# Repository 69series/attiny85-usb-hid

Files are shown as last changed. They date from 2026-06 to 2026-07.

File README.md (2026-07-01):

# ATtiny85 USB HID Keyboard

A fully custom USB HID keyboard dongle built on ATtiny85 — bare metal C firmware,
custom PCB designed in KiCad 10, no Arduino, no HAL, no bootloader abstractions.
Plug it into any USB port and it enumerates as a real HID keyboard device.

---

# ATtiny85 USB HID Keyboard








A fully custom USB HID keyboard dongle...

## What it does

Plugs directly into a USB-A port and acts as an autonomous HID keyboard.
Planned automation payloads (see `firmware/` for examples):

- One-click temp folder cleaner (`Win+R → %temp% → Ctrl+A → Shift+Del`)
- Stored credential injector (password manager dongle)
- Custom keyboard macro sequences
- Any HID keystroke automation — limited only by firmware logic

---

## Hardware

| Part | Value | Package |
|---|---|---|
| U1 | ATtiny85-20SU | SOIC-8 |
| R1, R2 | 68Ω | 1206 |
| R3 | 1.5kΩ (pull-up) | 1206 |
| R4 | 1.5kΩ (LED) | 1206 |
| C1 | 100nF | 0805 |
| D1, D2 | 3.6V Zener | SOD-123 |
| D3 | LED | 0402 |
| J1 | USB-FX | Custom PCB-edge footprint |

**PCB:** 31.31 × 11.8 × 0.8mm — slides directly into USB-A female socket.
Custom USB-FX footprint — PCB edge pads act as USB-A plug contacts.
Designed in KiCad 10. Ground pour on F.Cu.

**Schematic:** `docs/schematic.png`
**PCB Layout:** `docs/pcb.png`
**3D Render:** `docs/3dpcb_front.png` / `docs/3dpcb_back.png`
**Gerbers + BOM:** `hardware/fabrication/`

---

### Schematic
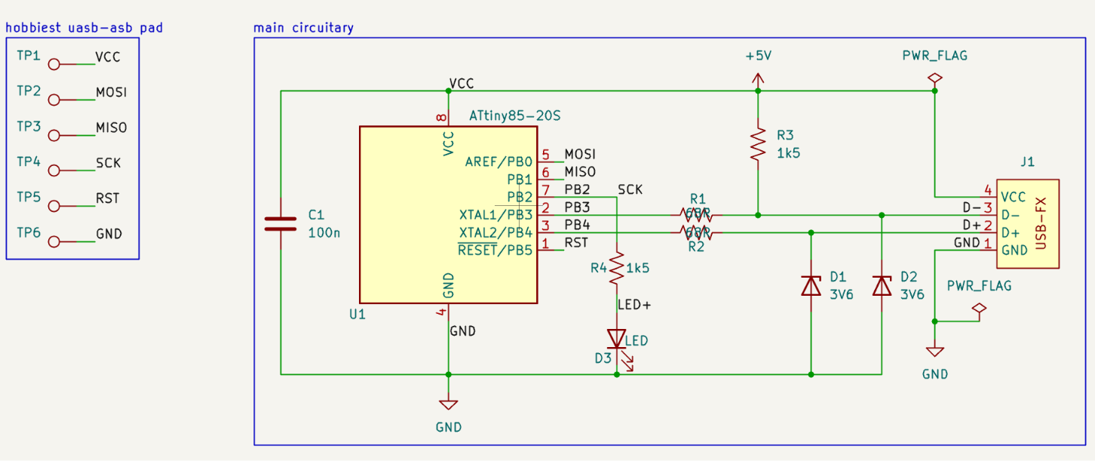
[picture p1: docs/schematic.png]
Schematic


### PCB Layout
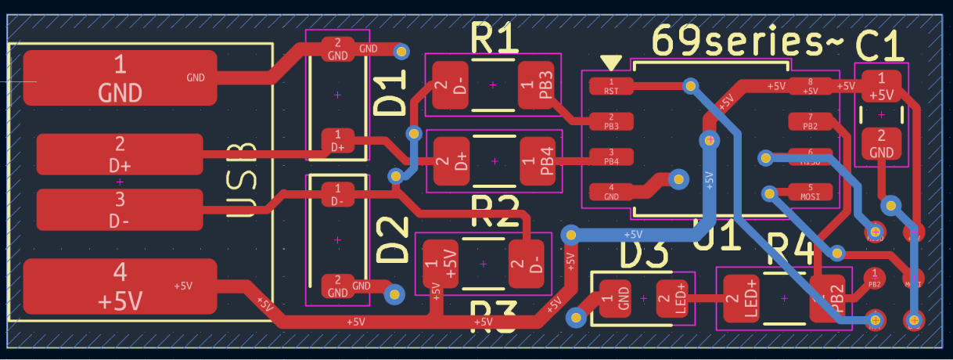
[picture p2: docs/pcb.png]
PCB Layout


### 3D Render
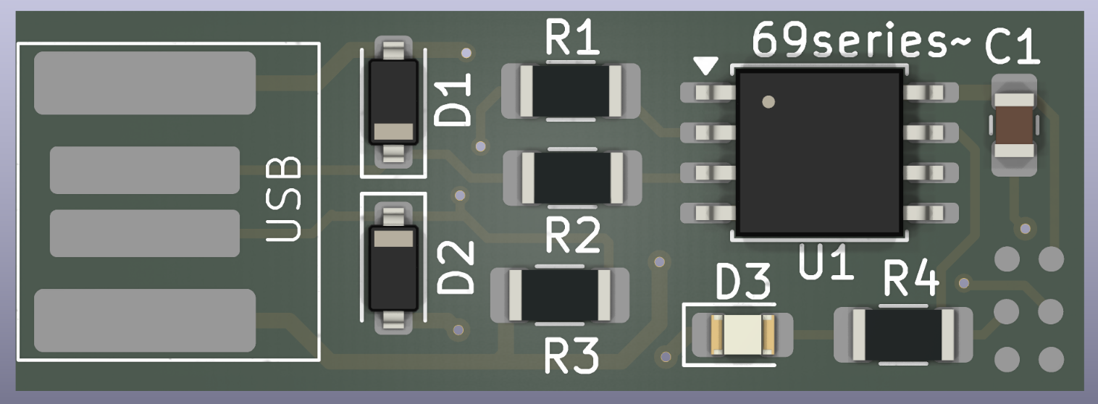
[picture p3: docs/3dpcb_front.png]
PCB Front

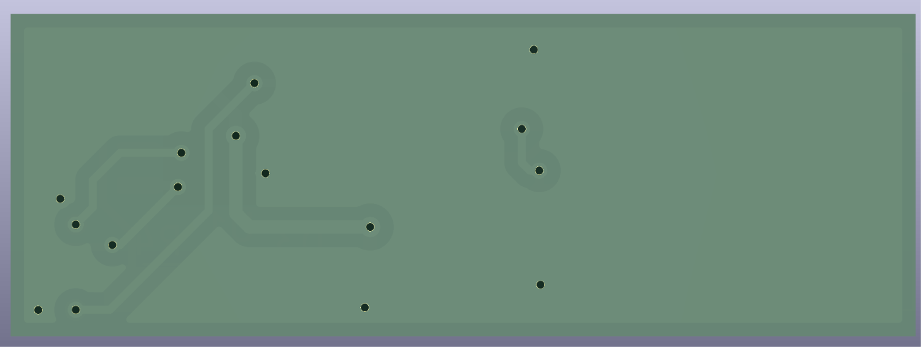
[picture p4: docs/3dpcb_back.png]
PCB Back


## Firmware

Pure bare-metal C. No Arduino core, no HAL, no bootloader.
Uses the V-USB library (obdev, v20121206) for software USB bit-banging on PB3/PB4.

**Toolchain:** avr-gcc (WinAVR), avrdude, VS Code

### Build and flash

```bash
cd firmware
make
make fuses
make flash
```

Or use the included automation script:

```bash
69s.bat -unlock -17A
```

### Fuse bits

```bash
avrdude -c usbasp -p attiny85 -U lfuse:w:0xE1:m -U hfuse:w:0xDD:m
```

- `lfuse 0xE1` — internal 16.5MHz PLL oscillator (required for V-USB timing)
- `hfuse 0xDD` — RESET enabled, SPI programming on

### Pin mapping

| ATtiny85 Pin | Function |
|---|---|
| PB3 (pin 2) | USB D− |
| PB4 (pin 3) | USB D+ |
| PB2 (pin 7) | Status LED |
| PB0 (pin 5) | ICSP MOSI / TP2 |
| PB1 (pin 6) | ICSP MISO / TP3 |
| PB2 (pin 7) | ICSP SCK / TP4 |
| PB5 (pin 1) | RESET / TP5 |

---

## Project Structure

```
attiny85-usb-hid/
├── docs/                     # Schematic, PCB renders, design notes
│   ├── schematic.png
│   ├── pcb.png
│   ├── 3dpcb_front.png
│   ├── 3dpcb_back.png
│   └── design-notes.md
├── firmware/                 # Bare metal C firmware
│   ├── main.c                # Main application
│   ├── usbconfig.h           # V-USB hardware configuration
│   ├── Makefile
│   ├── 69s.bat               # One-shot build+flash automation
│   └── usbdrv/               # V-USB library (obdev v20121206)
├── hardware/
│   ├── fabrication/          # Gerbers, BOM, positions for JLCPCB
│   │   ├── t85-gerber.zip
│   │   ├── bom.csv
│   │   └── positions.csv
│   ├── hardware_prototype/   # Prototype build photos, all versions
│   │   ├── spider_config.jpeg        # Initial 6-wire ICSP test setup
│   │   ├── vers_1_front.jpeg         # Version 1 prototype
│   │   ├── vers_1_back.jpeg
│   │   ├── final_cleanup_version_front.jpg  # Final build (PB4 hot-wired)
│   │   └── final_cleanup_version_back.jpg
│   ├── t85-usb.kicad_sch
│   ├── t85-usb.kicad_pcb
│   └── t85-usb.pdf
└── README.md
```
---

## Key Design Decisions

**Why ATtiny85?** 8-pin SOIC, 8KB flash, runs at 16.5MHz via internal PLL —
no external crystal needed, freeing PB3/PB4 for USB D+/D−.

**Why bare metal C?** Full control over every cycle. No Arduino abstraction layer,
no bootloader overhead. USB enumeration, HID descriptors, OSCCAL calibration —
all implemented and understood at the register level.

**Why V-USB?** ATtiny85 has no hardware USB peripheral. V-USB bit-bangs USB
low-speed (1.5 Mbit/s) in software using hand-tuned AVR assembly timed to
the exact cycle. This is the same approach used by Digispark.

**USB signal conditioning:** ATtiny85 GPIO swings 0–5V but USB data lines
must not exceed 3.3V. D1/D2 (3.6V zeners) clamp the high state.
R1/R2 (68Ω) provide impedance matching for the transmission line.

**OSCCAL runtime calibration:** Internal RC oscillator has ±10% factory
tolerance. V-USB requires ±1% at 16.5MHz. `calibrateOscillator()` uses
`usbMeasureFrameLength()` on every power-up to tune OSCCAL to the exact
live USB SOF timing, ensuring reliable enumeration regardless of temperature
or chip-to-chip variance.

**VID/PID:** Uses V-USB's shared free VID/PID pool (0x16C0 / 0x27DB).
Appropriate for open-source/personal projects per obdev's usage terms.

**Double enumeration init:** Two disconnect/reconnect cycles on startup —
the first lets the host settle/timeout on an initial connection attempt,
the second is the real enumeration. This mirrors the bootloader-exit →
user-program-start transition pattern and significantly improves
host compatibility, particularly on modern xHCI controllers.

**Windows driver binding:** Chose PID 0x27DB (matching Digispark's HID
keyboard PID) to ensure Windows binds the device to `hidusb.sys` (the
native HID class driver) rather than `libusb0.sys`. This is critical —
a generic libusb driver does not poll the interrupt-IN endpoint at the OS
level, so keystrokes never reach the active application regardless of
how correctly the USB descriptors enumerate.

---

## Host Compatibility

Tested and working:

| Host | Result |
|---|---|
| Windows 11 (ASUS TUF F15, xHCI) | ✅ Full enumeration, keystrokes delivered |
| Android (Redmi Note 10 Pro, OTG) | ✅ Working |
| Android (Redmi 6, OTG) | ⚠️ Enumeration succeeds, keystrokes inconsistent |

---

## Prototype Notes

Built and tested on perfboard before PCB fabrication.
`hardware/prototype/spider_config.jpeg` shows the initial 6-wire ICSP
test harness soldered directly to the chip legs before any perfboard work.
`final_cleanup_version_*` shows the final prototype — PB4 (USB D+) pin
was damaged during rework and required a fine wire hot-fix, which held
reliably through all testing.

---

### Prototype Photos
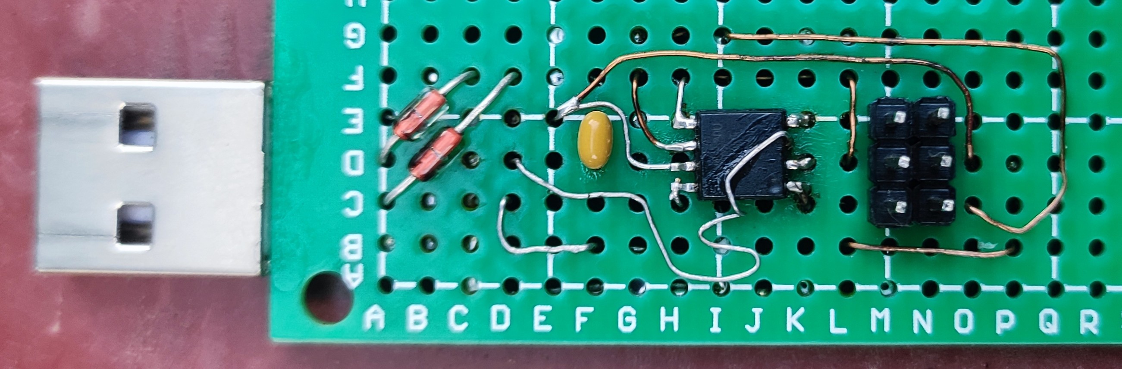
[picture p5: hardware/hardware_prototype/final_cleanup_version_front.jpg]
Final Prototype Front

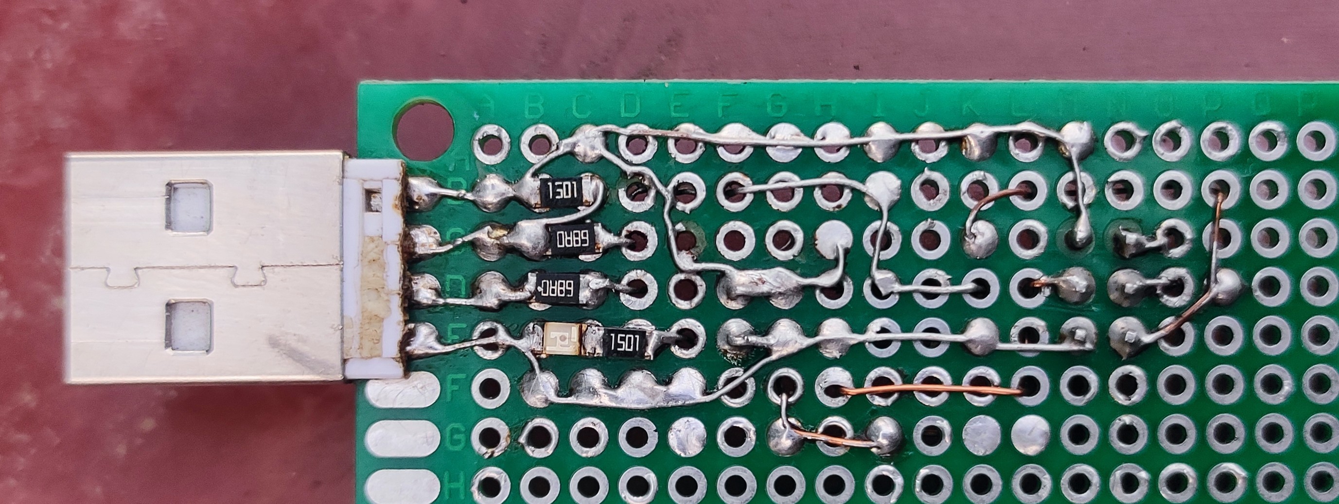
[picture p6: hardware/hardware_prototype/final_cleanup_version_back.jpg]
Final Prototype Back


---
## Debugging Journey

This project involved deep debugging across hardware, firmware, toolchain,
and host-compatibility layers. Notable findings:

- **OSCCAL drift** caused intermittent enumeration — solved with runtime
  calibration using `usbMeasureFrameLength()`
- **Windows driver binding** (libusb0 vs hidusb) was the root cause of
  keystrokes never arriving despite correct USB enumeration — identified
  by comparing working Digispark sketch logs against our own via UsbTreeView
- **xHCI interrupt-IN scheduling** behaves differently from legacy UHCI/OHCI
  for low-speed software-USB devices — characterized and worked around via
  double enumeration cycle and correct PID selection

Full debugging notes in `docs/design-notes.md`.

---

## Future Work

- [ ] Example firmware payloads (temp cleaner, credential injector, macro runner)
- [ ] PCB fabrication and SMD assembly at JLCPCB
- [ ] ICSP test pad verification on real PCB
- [ ] v2.0 PCB with ICSP pads on back copper for in-circuit reprogramming

---

## Author

**Narendra Sagolsem** — Electronics Engineer
Portfolio: [s69series-3-0.vercel.app](https://s69series-3-0.vercel.app)
GitHub: [69series](https://github.com/69series)

---

## License

Firmware: MIT
V-USB library: GPL v2 — see `firmware/usbdrv/License.txt`
Hardware: CERN-OHL-S v2

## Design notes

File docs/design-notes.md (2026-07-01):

# Design Notes — ATtiny85 USB HID

## Overview
Minimal USB HID device based on ATtiny85 using V-USB software USB library.
Designed as a bare-metal C project, no Arduino or HAL abstractions.

## IC Selection — ATtiny85
- 8-pin SOIC package, 8KB flash, 512B SRAM
- No hardware USB peripheral — USB handled via V-USB in firmware
- Internal 16.5MHz PLL oscillator used — no external crystal needed
- Frees PB3/PB4 from XTAL duty for USB D+/D- lines

## Fuse Bits
- lfuse: 0xE1 — internal PLL clock 16.5MHz
- hfuse: 0xDD — RESET enabled, SPI programming on
- Program with: `avrdude -c usbasp -p attiny85 -U lfuse:w:0xE1:m -U hfuse:w:0xDD:m`

## USB Signal Path
- D- (USB pad 2) → R1 68Ω → PB3 (pin 2)
- D+ (USB pad 3) → R2 68Ω → PB4 (pin 3)
- Zener diodes D1/D2 3.6V clamp 5V GPIO swing to USB-safe 3.3V max
- R4 1.5kΩ pull-up on D+ for host device detection

## V-USB Configuration
In usbconfig.h set:
- USB_CFG_DPLUS_BIT 3 (PB3)
- USB_CFG_DMINUS_BIT 4 (PB4)

## PCB Design Decisions
- Board dimensions: 31.31×11.8mm — fits inside USB-A female socket
- PCB thickness: 0.8mm — required for USB-A insertion (standard is 1.6mm)
- All SMD components 0402 — fits tight boarLd dimensions
- Zeners in SOD-123 package
- Ground pour on F.Cu — improves signal integrity and simplifies routing
- Custom USB-FX footprint — PCB edge pads act as USB-A plug contact

## Bill of Materials
| Reference | Value | Package |
|---|---|---|
| U1 | ATtiny85-20SU | SOIC-8 |
| R1, R2 | 68Ω | 1206 |
| R3 | 1.5kΩ | 1206 |
| R4 | 1.5kΩ | 1206 |
| C1 | 100nF | 0805 |
| D1, D2 | 3.6V Zener | SOD-123 |
| D3 | LED | 0402 |
| U2 | USB-FX | Custom |

## Programming
Flash chip before soldering using USBasp programmer on breadboard.
No bootloader needed — pure bare metal.

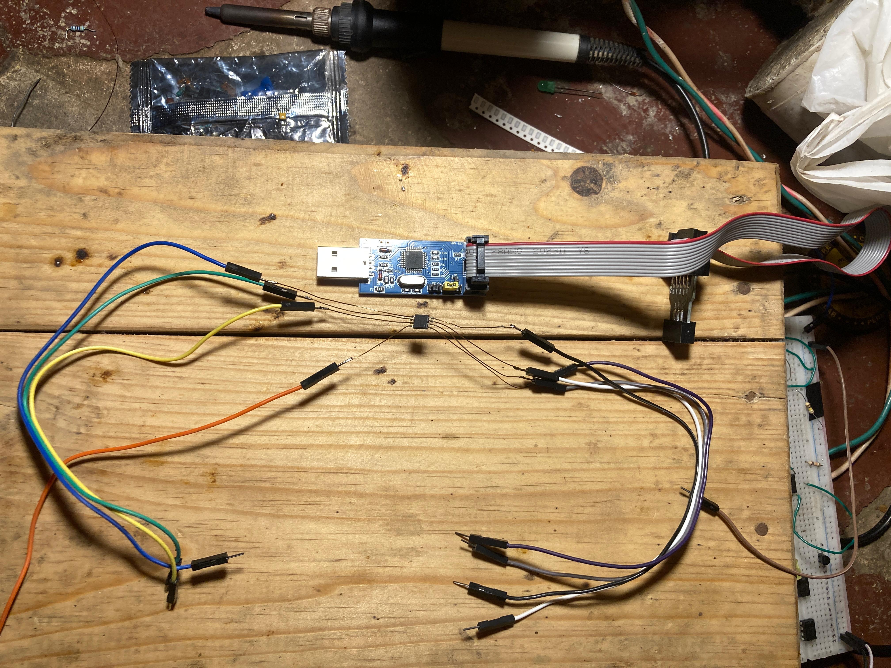
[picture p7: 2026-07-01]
hardware/hardware_prototype/spider_config.jpeg

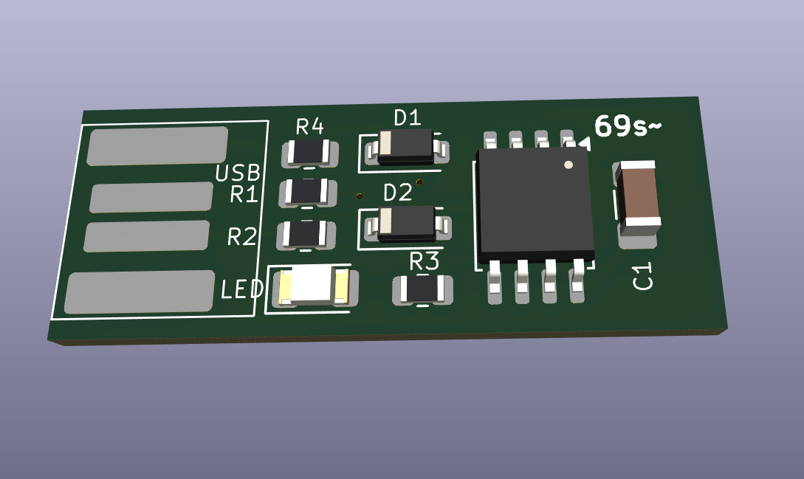
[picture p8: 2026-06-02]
hardware/pcb-layout.png

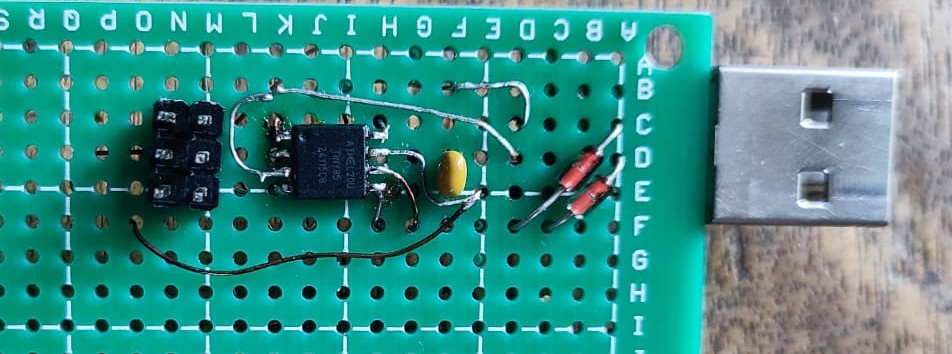
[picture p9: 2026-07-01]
hardware/hardware_prototype/vers_1_front.jpeg

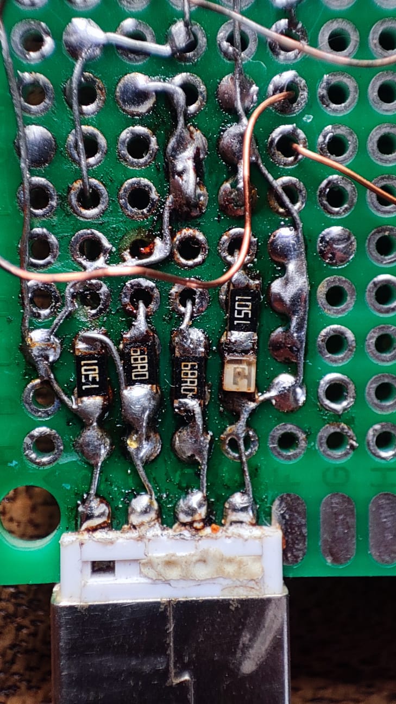
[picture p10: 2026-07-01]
hardware/hardware_prototype/vers_1_back_close_view.jpeg

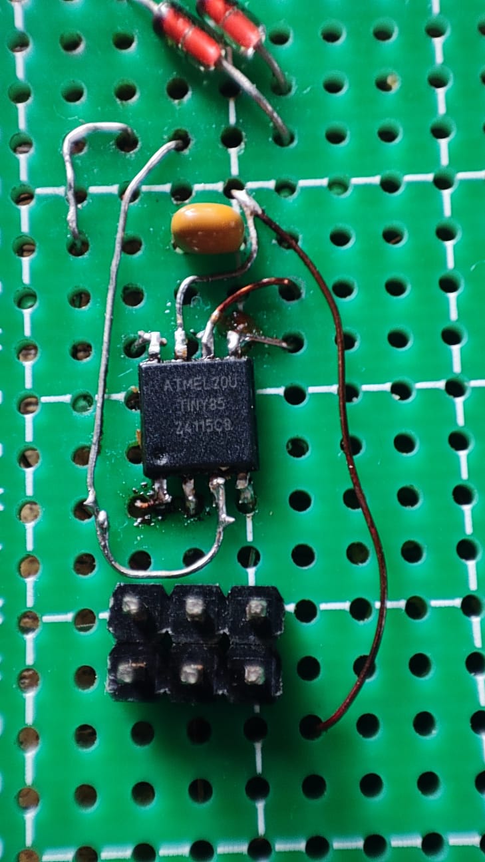
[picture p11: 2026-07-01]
hardware/hardware_prototype/vers_1_front_close_view.jpeg

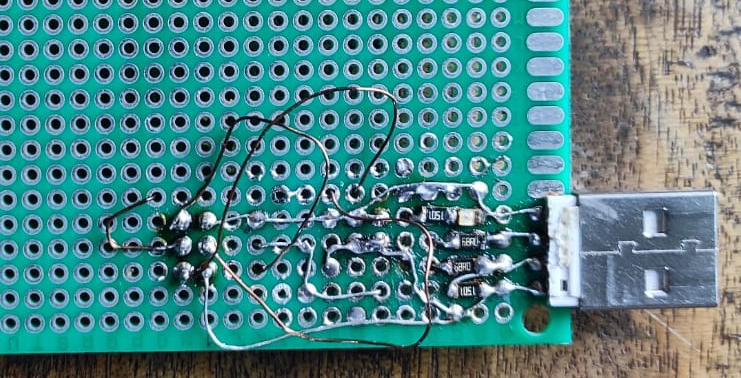
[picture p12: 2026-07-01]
hardware/hardware_prototype/vers_1_back.jpeg

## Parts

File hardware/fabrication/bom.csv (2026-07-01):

Designator | Footprint | Quantity | Value | LCSC Part #
C1 | 0805 | 1 | 100n
D1, D2 | D_SOD-123 | 2 | 3V6
D3 | 0805 | 1 | LED
J1 | USB-FX | 1 | ~
R1, R2 | 1206 | 2 | 68R
R3, R4 | 1206 | 2 | 1k5
TP1, TP2, TP3, TP4, TP5, TP6 | pad-0-8mm69s | 6 | TestPoint
U1 | SOIC-8_5.3x5.3mm_P1.27mm | 1 | ATtiny85-20S

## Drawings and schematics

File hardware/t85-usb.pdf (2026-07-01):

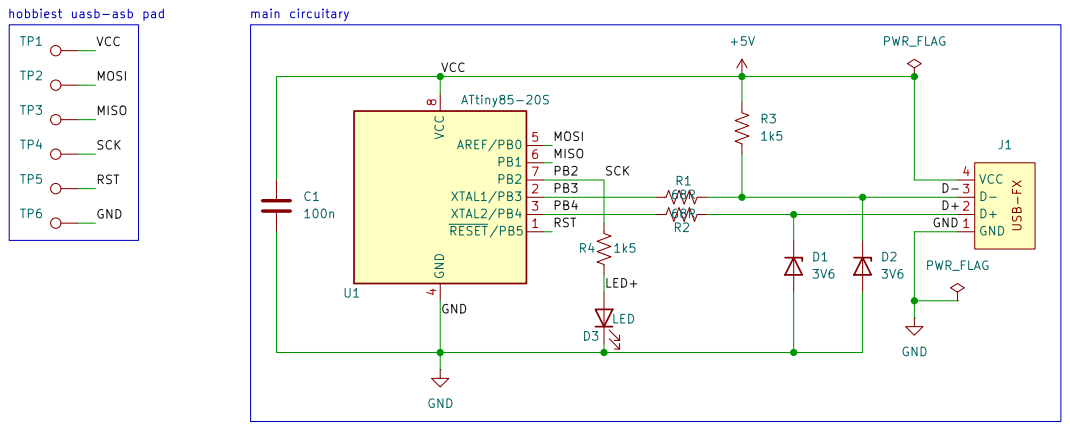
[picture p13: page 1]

Size: A4 | Rev: 2.5
KiCad E.D.A. 10.0.1 | Id: 1/1

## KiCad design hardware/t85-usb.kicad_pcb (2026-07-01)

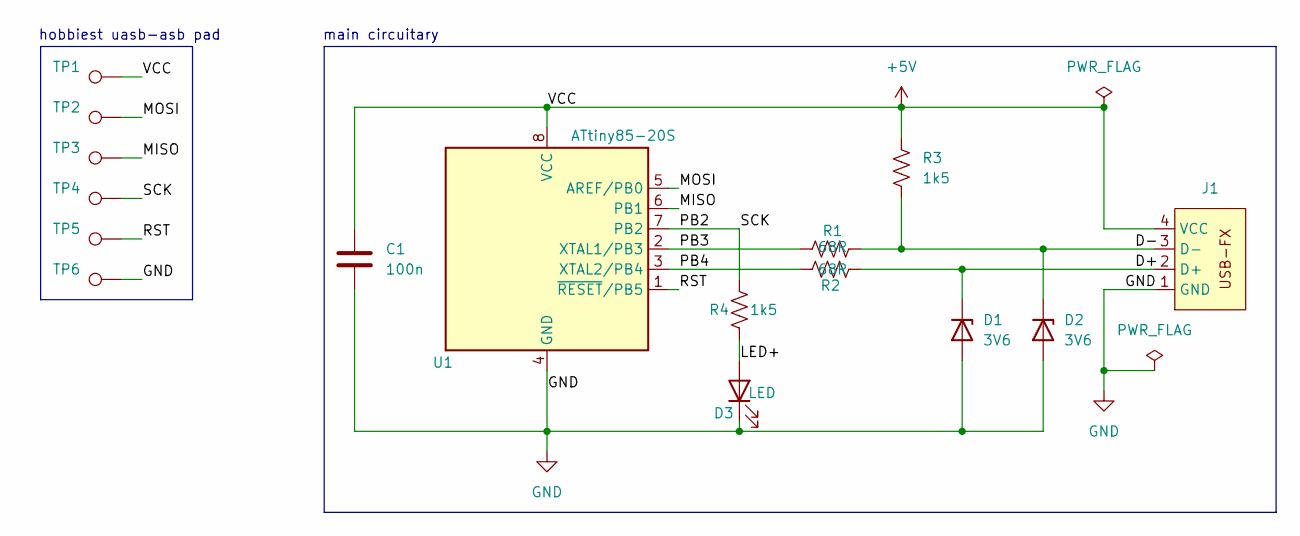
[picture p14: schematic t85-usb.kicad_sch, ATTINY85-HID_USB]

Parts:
C1: 100n; C_0805_2012Metric_Pad1.18x1.45mm_HandSolder
D1, D2: 3V6; D_SOD-123
D3: LED; LED_0805_2012Metric_Pad1.15x1.40mm_HandSolder
J1: USB-FX
R1, R2: 68R; R_1206_3216Metric_Pad1.30x1.75mm_HandSolder
R3, R4: 1k5; R_1206_3216Metric_Pad1.30x1.75mm_HandSolder
TP1, TP2, TP3, TP4, TP5, TP6: TestPoint; pad-0-8mm69s
U1: ATtiny85-20S; SOIC-8_5.3x5.3mm_P1.27mm

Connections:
+5V: C1.1, J1.4 (VCC), R3.1, TP1.1 (1_1), U1.8 (VCC)
/D+: D1.1 (K), J1.2 (D+), R2.2
/D-: D2.1 (K), J1.3 (D-), R1.2, R3.2
/LED+: D3.2 (A), R4.2
/MISO: TP3.1 (1_1), U1.6 (PB1)
/MOSI: TP2.1 (1_1), U1.5 (AREF/PB0)
/PB2: R4.1, TP4.1 (1_1), U1.7 (PB2)
/PB3: R1.1, U1.2 (XTAL1/PB3)
/PB4: R2.1, U1.3 (XTAL2/PB4)
/RST: TP5.1 (1_1), U1.1 (~RESET/PB5)
GND: C1.2, D1.2 (A), D2.2 (A), D3.1 (K), J1.1 (GND), TP6.1 (1_1), U1.4 (GND)

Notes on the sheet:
main circuitary
hobbiest uasb-asb pad

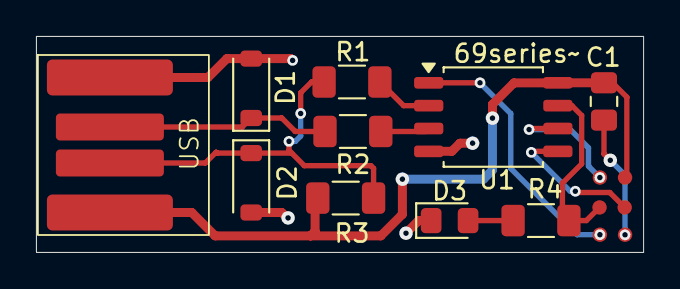
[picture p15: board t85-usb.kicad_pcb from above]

Board: 2 copper layers, 33.7 x 12.0 mm, 16 parts (0 on the bottom side), 11 nets.

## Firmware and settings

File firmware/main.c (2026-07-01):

/*
ATtiny85 USB HID Keyboard - Custom Firmware
Author: Narendra Sagolsem
PB3=USB D-, PB4=USB D+, PB2=LED
*/

#include <avr/io.h>
#include <avr/interrupt.h>
#include <avr/pgmspace.h>
#include <util/delay.h>
#include <string.h>
#include "usbdrv/usbdrv.h"

const PROGMEM char usbHidReportDescriptor[45] = {
    0x05,0x01,0x09,0x06,0xA1,0x01,0x05,0x07,
    0x19,0xE0,0x29,0xE7,0x15,0x00,0x25,0x01,
    0x75,0x01,0x95,0x08,0x81,0x02,0x95,0x01,
    0x75,0x08,0x81,0x03,0x95,0x06,0x75,0x08,
    0x15,0x00,0x25,0x65,0x05,0x07,0x19,0x00,
    0x29,0x65,0x81,0x00,0xC0
};

typedef struct {
    uint8_t modifier;
    uint8_t reserved;
    uint8_t keycode[6];
} KeyReport;

static KeyReport reportBuffer;
static uint8_t idleRate;

/* Modifier keys */
#define MOD_LCTRL   0x01
#define MOD_LSHIFT  0x02
#define MOD_LALT    0x04
#define MOD_LGUI    0x08

/* Keycodes */
#define KEY_ENTER   0x28
#define KEY_ESC     0x29
#define KEY_TAB     0x2B
#define KEY_SPACE   0x2C
#define KEY_F11     0x44

/* Global blink counter for task LED rhythm */
static uint16_t blinkCounter = 0;
static uint8_t taskRunning = 0;   /* 0=init phase, 1=task phase */

usbMsgLen_t usbFunctionSetup(uint8_t data[8]) {
    usbRequest_t *rq = (usbRequest_t *)data;
    if((rq->bmRequestType & USBRQ_TYPE_MASK) == USBRQ_TYPE_CLASS) {
        if(rq->bRequest == USBRQ_HID_GET_REPORT) {
            usbMsgPtr = (void *)&reportBuffer;
            return sizeof(reportBuffer);
        } else if(rq->bRequest == USBRQ_HID_GET_IDLE) {
            usbMsgPtr = &idleRate;
            return 1;
        } else if(rq->bRequest == USBRQ_HID_SET_IDLE) {
            idleRate = rq->wValue.bytes[1];
        }
    }
    return 0;
}

/* 16.5MHz crystal timing calibration */
void calibrateOscillator(void) {
    uchar step = 128;
    uchar trialValue = 0, optimumValue;
    int x, optimumDev,
        targetValue = (unsigned)(1499 * (double)F_CPU / 10.5e6 + 0.5);
    do {
        OSCCAL = trialValue + step;
        x = usbMeasureFrameLength();
        if(x < targetValue) trialValue += step;
        step >>= 1;
    } while(step > 0);
    optimumValue = trialValue;
    optimumDev = x;
    for(OSCCAL = trialValue - 1; OSCCAL <= trialValue + 1; OSCCAL++) {
        x = usbMeasureFrameLength() - targetValue;
        if(x < 0) x = -x;
        if(x < optimumDev) { optimumDev = x; optimumValue = OSCCAL; }
    }
    OSCCAL = optimumValue;
}


/* poll-safe delay - auto blinks LED every 50ms during task phase */
void pollDelay(uint16_t ms) {
    for(uint16_t i = 0; i < ms; i++) {
        usbPoll();
        _delay_ms(1);

        if(taskRunning) {
            blinkCounter++;
            if(blinkCounter >= 50) {  /* 50ms blink */
                PORTB ^= (1 << PB2);   /* toggle LED */
                blinkCounter = 0;
            }
        }
    }
}


/* blink used ONLY for init and done signals */
void blinkLED(uint8_t times, uint16_t ms) {
    taskRunning = 0;   /* pause auto-blink during manual blink */
    for(uint8_t i = 0; i < times; i++) {
        PORTB |=  (1 << PB2);
        pollDelay(ms);
        PORTB &= ~(1 << PB2);
        pollDelay(ms);
    }
}

void ledOff(void) { PORTB &= ~(1 << PB2); }

void sendNull(void) {
    while(!usbInterruptIsReady()) { usbPoll(); _delay_ms(5); }
    memset(&reportBuffer, 0, sizeof(reportBuffer));
    usbSetInterrupt((void *)&reportBuffer, sizeof(reportBuffer));
}

void sendKey(uint8_t modifier, uint8_t keycode) {
    while(!usbInterruptIsReady()) { usbPoll(); _delay_ms(5); }
    memset(&reportBuffer, 0, sizeof(reportBuffer));
    reportBuffer.modifier   = modifier;
    reportBuffer.keycode[0] = keycode;
    usbSetInterrupt((void *)&reportBuffer, sizeof(reportBuffer));

    while(!usbInterruptIsReady()) { usbPoll(); _delay_ms(5); }
    memset(&reportBuffer, 0, sizeof(reportBuffer));
    usbSetInterrupt((void *)&reportBuffer, sizeof(reportBuffer));
    _delay_ms(30);
}

void sendString(const char *str) {
    while(*str) {
        char c = *str++;
        uint8_t kc = 0, mod = 0;
        if     (c>='a'&&c<='z') { kc = 4+(c-'a'); }
        else if(c>='A'&&c<='Z') { kc = 4+(c-'A'); mod = MOD_LSHIFT; }
        else if(c>='1'&&c<='9') { kc = 30+(c-'1'); }
        else if(c=='0')         { kc = 39; }
        else if(c==' ')         { kc = KEY_SPACE; }
        else if(c=='\n')        { kc = KEY_ENTER; }
        else if        (c=='.') { kc = 55; }
        else if        (c=='/') { kc = 56; }
        else if        (c==':') { kc = 51; mod = MOD_LSHIFT; }
        else if (c == '#') { kc = 32; mod = MOD_LSHIFT; }
        if(kc) sendKey(mod, kc);
        _delay_ms(20);
    }
}

/* ─────────────────────────────────────────── */

int main(void) {
    DDRB  |=  (1 << PB2);
    PORTB &= ~(1 << PB2);

    /* ── USB INIT ── */
    cli();
    usbDeviceDisconnect();
    pollDelay(250);
    usbDeviceConnect();
    usbInit();
    calibrateOscillator();
    sei();

    /* first-char fix pass 1 */
    sendNull();

    /* 2x quick blink = ready signal (init phase, no auto-blink) */
    blinkLED(2, 50);
    pollDelay(100);

    /* first-char fix pass 2 */
    sendNull();

    /* ── START TASK PHASE - auto blink begins now ── */
    taskRunning = 1;
    blinkCounter = 0;

    /* AUTOMATION TASK ------------------- */
    /* Win+R → cmd → Enter */
    pollDelay(5);
    sendKey(MOD_LGUI, 0x15);
    pollDelay(100);
    sendString("cmd");
    pollDelay(100);
    sendKey(0, KEY_ENTER);
    pollDelay(400);

    sendString("FIRMWARE DESIGN BY NARENDRA SAGOLSEM");
    pollDelay(100);
    sendKey(0, KEY_ENTER);
    pollDelay(800);

    /* TASK DONE------------------- */

    /* stop auto-blink, clean LED state */
    taskRunning = 0;
    ledOff();

    /* 5x slow blink = done! */
    blinkLED(5, 900);
    ledOff();

    while(1) { usbPoll(); }
    return 0;
}

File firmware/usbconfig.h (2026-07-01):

/* USB configuration for ATtiny85 V-USB HID */

#define USB_CFG_IOPORTNAME      B
#define USB_CFG_DMINUS_BIT      3
#define USB_CFG_DPLUS_BIT       4

#define USB_CFG_CLOCK_KHZ       (F_CPU/1000)

#define USB_CFG_CHECK_CRC       0
#define USB_CFG_MAX_BUS_POWER   100
#define USB_CFG_IMPLEMENT_FN_WRITE  0
#define USB_CFG_IMPLEMENT_FN_READ   0
#define USB_CFG_IMPLEMENT_FN_WRITEOUT 0
#define USB_CFG_HAVE_FLOWCONTROL    0
#define USB_CFG_DRIVER_FLASH_PAGE   0
#define USB_CFG_LONG_TRANSFERS      0
#define USB_CFG_DEVICE_CLASS        0
#define USB_CFG_DEVICE_SUBCLASS     0
#define USB_CFG_INTERFACE_CLASS     3
#define USB_CFG_INTERFACE_SUBCLASS  1
#define USB_CFG_INTERFACE_PROTOCOL  1
#define USB_CFG_HID_REPORT_DESCRIPTOR_LENGTH 45

#define USB_CFG_VENDOR_ID       0xc0, 0x16
#define USB_CFG_DEVICE_ID       0xdb, 0x27
#define USB_CFG_DEVICE_VERSION  0x00, 0x01
#define USB_CFG_VENDOR_NAME     'N','a','r','e','n','d','r','a'
#define USB_CFG_VENDOR_NAME_LEN 8
#define USB_CFG_DEVICE_NAME     '6','9','s','H','I','D','K','e','y'
#define USB_CFG_DEVICE_NAME_LEN 9
#define USB_CFG_DEVICE_CLASS    0
#define USB_CFG_IS_SELF_POWERED 0
#define USB_CFG_IMPLEMENT_HALT  0
#define USB_CFG_SUPPRESS_INTR_CODE 0
#define USB_CFG_INTR_POLL_INTERVAL 10
#define USB_CFG_HAVE_INTRIN_ENDPOINT 1
#define USB_CFG_HAVE_INTRIN_ENDPOINT3 0

#define USB_CFG_HAVE_MEASURE_FRAME_LENGTH   1

#define USB_CFG_EP3_NUMBER      3
#define USB_CFG_DESCR_PROPS_DEVICE 0
#define USB_CFG_DESCR_PROPS_CONFIGURATION 0
#define USB_CFG_DESCR_PROPS_STRINGS 0
#define USB_CFG_DESCR_PROPS_STRING_0 0
#define USB_CFG_DESCR_PROPS_STRING_VENDOR 0
#define USB_CFG_DESCR_PROPS_STRING_DEVICE 0
#define USB_CFG_DESCR_PROPS_HID 0
#define USB_CFG_DESCR_PROPS_HID_REPORT 0
#define USB_CFG_DESCR_PROPS_UNKNOWN 0

/* ATtiny85 uses Pin Change Interrupt instead of INT0 */
#define USB_INTR_CFG            PCMSK
#define USB_INTR_CFG_SET        (1 << USB_CFG_DPLUS_BIT)
#define USB_INTR_CFG_CLR        0
#define USB_INTR_ENABLE         GIMSK
#define USB_INTR_ENABLE_BIT     PCIE
#define USB_INTR_PENDING        GIFR
#define USB_INTR_PENDING_BIT    PCIF
#define USB_INTR_VECTOR         PCINT0_vect

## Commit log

2026-06-02 feat: initial hardware design - ATtiny85 USB HID PCB
    [at-85-remake-B_Cu.gbr, at-85-remake-B_Mask.gbr, at-85-remake-B_Paste.gbr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]
2026-07-01 docs: final README, design notes, project cleanup
    [at-85-remake-B_Cu.gbr, at-85-remake-B_Mask.gbr, at-85-remake-B_Paste.gbr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]

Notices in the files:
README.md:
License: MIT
